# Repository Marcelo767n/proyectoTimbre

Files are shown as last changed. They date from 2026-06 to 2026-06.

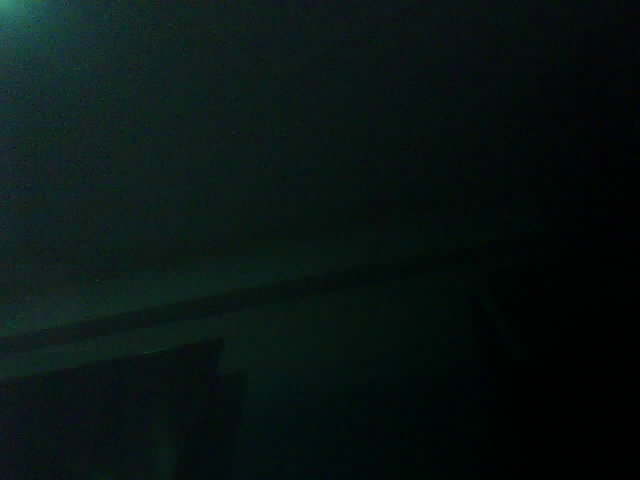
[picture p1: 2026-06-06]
capturas/foto_timbre_20260605_232243.jpg

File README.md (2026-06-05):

# 🔔 Proyecto Timbre Inteligente

Repositorio oficial con la documentación, diseño y código del prototipo de timbre inteligente. Este proyecto se desarrolla para las materias de **Sistemas Embebidos 2** y **Prototipado Rápido**.

---

## 🎯 Objetivo del Proyecto

Diseñar y construir el prototipo de un timbre inteligente basado en una placa de circuito impreso (PCB) personalizada. El sistema captura la presencia de visitantes y gestiona la información de forma remota a través de una interfaz web centralizada.

---

## ⚙️ Arquitectura del Sistema

El proyecto destaca por su capacidad de comunicación remota. Los módulos **no necesitan estar conectados a la misma red Wi-Fi**, ya que la transferencia de datos se realiza a través de Internet.

### 1. Módulo del Timbre (Cliente)
* **Hardware:** ESP32-CAM integrado en una PCB propia diseñada en **KiCad**.
* **Firmware:** Desarrollado en el framework profesional **ESP-IDF** utilizando el entorno de **PlatformIO**.
* **Función:** Al presionar el timbre, el dispositivo se conecta a la red Wi-Fi local (Red A), captura una fotografía del visitante y la envía mediante una petición **HTTP POST** hacia el servidor remoto.

### 2. Módulo de Gestión (Servidor e Interfaz Web)
* **Hardware:** Raspberry Pi.
* **Backend:** Desarrollado en **Python**. Actúa como servidor web central conectado a Internet (Red B) para recibir las peticiones HTTP del timbre y procesar las imágenes.
* **Frontend:** Cuenta con una **interfaz web dedicada** que permite visualizar las fotografías tomadas y consultar los datos de los visitantes en tiempo real.
* **Almacenamiento:** Guarda el historial de visitas de forma estructurada en archivos independientes con formato `.csv` (un archivo `.csv` por cada timbre registrado).

---

## 📊 Datos Registrados

Por cada interacción con el timbre, el sistema procesa y despliega en la interfaz web:
* 📸 Fotografía del visitante.
* 📅 Fecha y hora exacta del evento.
* 🆔 Identificador único del timbre (soporte multi-timbre).

---

## 🛠️ Tecnologías y Herramientas

* **Hardware Base:** ESP32-CAM & Raspberry Pi
* **Diseño Electrónico:** KiCad (Diseño y ruteo de la placa PCB)
* **Entorno de Desarrollo (Firmware):** PlatformIO + ESP-IDF (C/C++)
* **Entorno de Desarrollo (Servidor):** Python
* **Protocolo de Comunicación:** HTTP (Transmisión optimizada de imágenes y metadatos)
* **Base de Datos:** Archivos de texto plano (.CSV) independientes por dispositivo

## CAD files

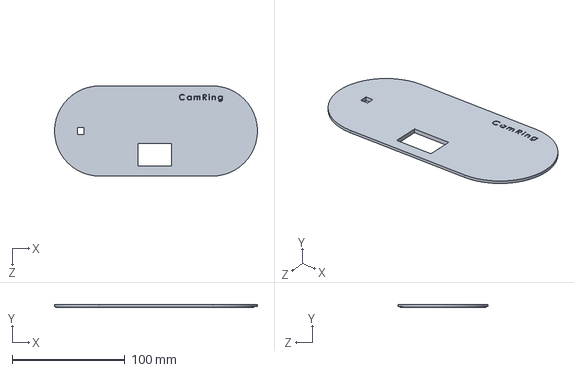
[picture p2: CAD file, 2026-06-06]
diseñoCarcasa/tapa.SLDPRT
180.0 x 3.00 x 80.0 mm

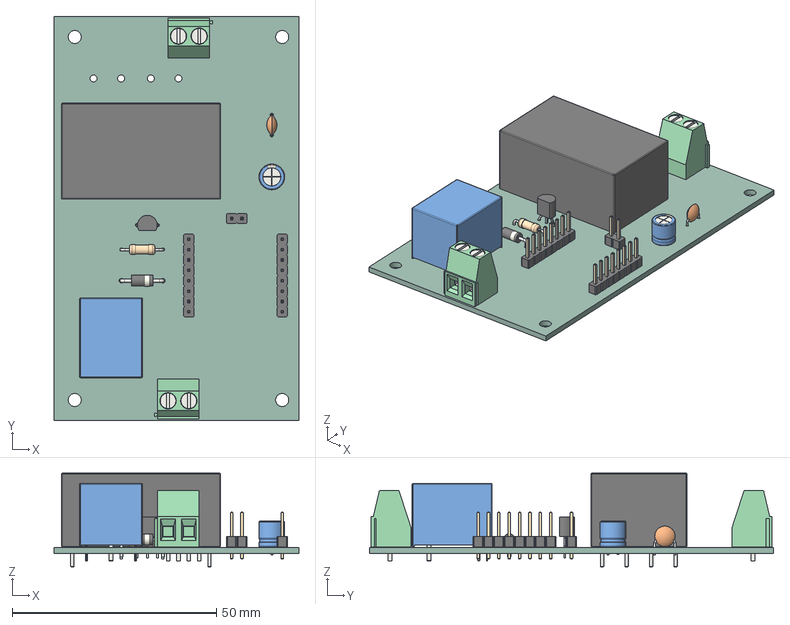
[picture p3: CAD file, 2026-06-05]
pcb/placaTimbre/placaTimbre.step
60.0 x 99.1 x 23.0 mm
D_DO-41_SOD81_P10.16mm_Horizontal
TO-92_Inline_Wide
PinHeader_1x08_P2.54mm_Vertical x 2
Converter_ACDC_Hi-Link_HLK-5Mxx
TerminalBlock_Phoenix_MKDS-1,5-2-5.08_1x02_P5.08mm_Horizontal x 2
PinHeader_1x02_P2.54mm_Vertical
CP_Radial_D6.3mm_P2.50mm
R_Axial_DIN0207_L6.3mm_D2.5mm_P10.16mm_Horizontal
Relay_SPDT_SANYOU_SRD_Series_Form_C
C_Disc_D5.0mm_W2.5mm_P5.00mm
placaTimbre_PCB

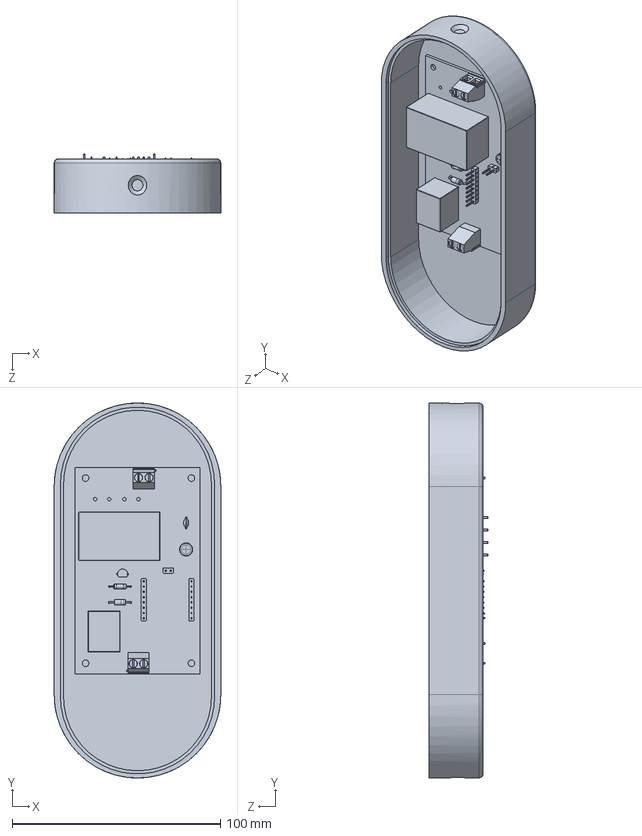
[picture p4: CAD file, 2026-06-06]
diseñoCarcasa/timbre1.SLDPRT
80.0 x 180.0 x 28.3 mm

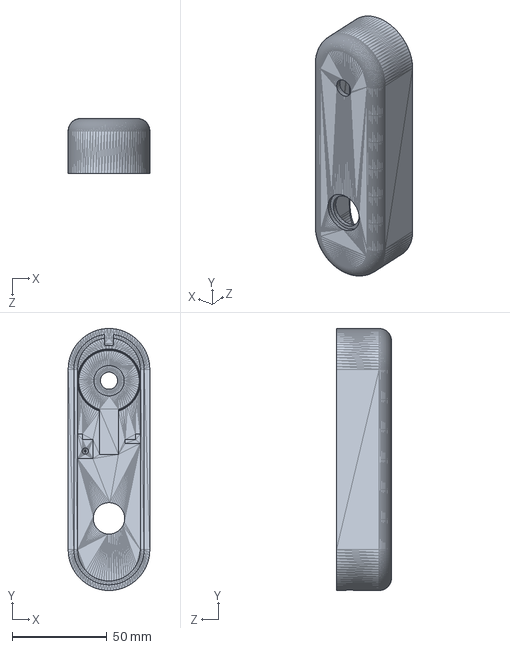
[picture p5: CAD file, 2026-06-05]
diseñoCarcasa/doorbell front v12.SLDPRT
43.0 x 138.0 x 29.0 mm

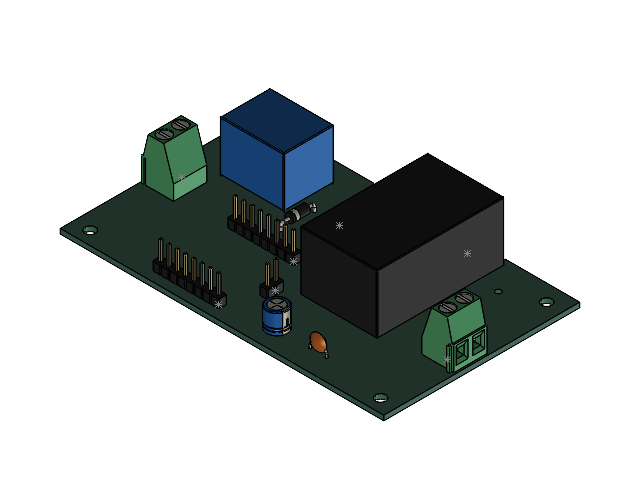
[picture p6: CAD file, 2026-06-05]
diseñoCarcasa/placaTimbre.SLDASM
D_DO-41_SOD81_P10.16mm_Horizontal.step
TO-92_Inline_Wide.step
PinHeader_1x08_P2.54mm_Vertical.step x 2
Converter_ACDC_Hi-Link_HLK-5Mxx.step
TerminalBlock_Phoenix_MKDS-1,5-2-5.08_1x02_P5.08mm_Horizontal.step x 2
PinHeader_1x02_P2.54mm_Vertical.step
CP_Radial_D6.3mm_P2.50mm.step
R_Axial_DIN0207_L6.3mm_D2.5mm_P10.16mm_Horizontal.step
Relay_SPDT_SANYOU_SRD_Series_Form_C.step
C_Disc_D5.0mm_W2.5mm_P5.00mm.step
placaTimbre_PCB.step

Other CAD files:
diseñoCarcasa/timbre.SLDPRT
diseñoCarcasa/placaTimbre.SLDPRT

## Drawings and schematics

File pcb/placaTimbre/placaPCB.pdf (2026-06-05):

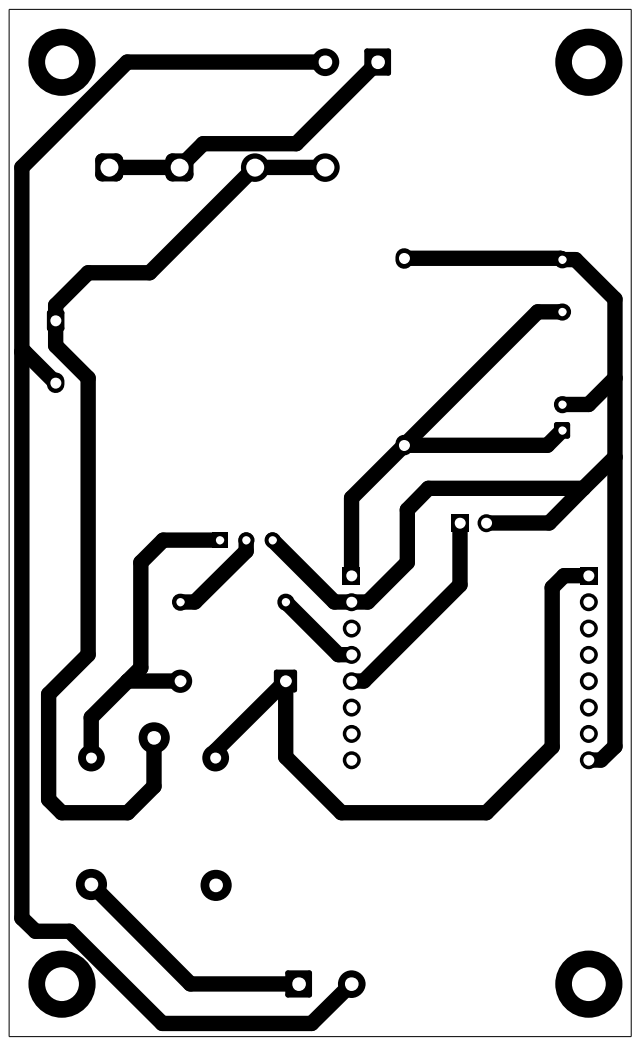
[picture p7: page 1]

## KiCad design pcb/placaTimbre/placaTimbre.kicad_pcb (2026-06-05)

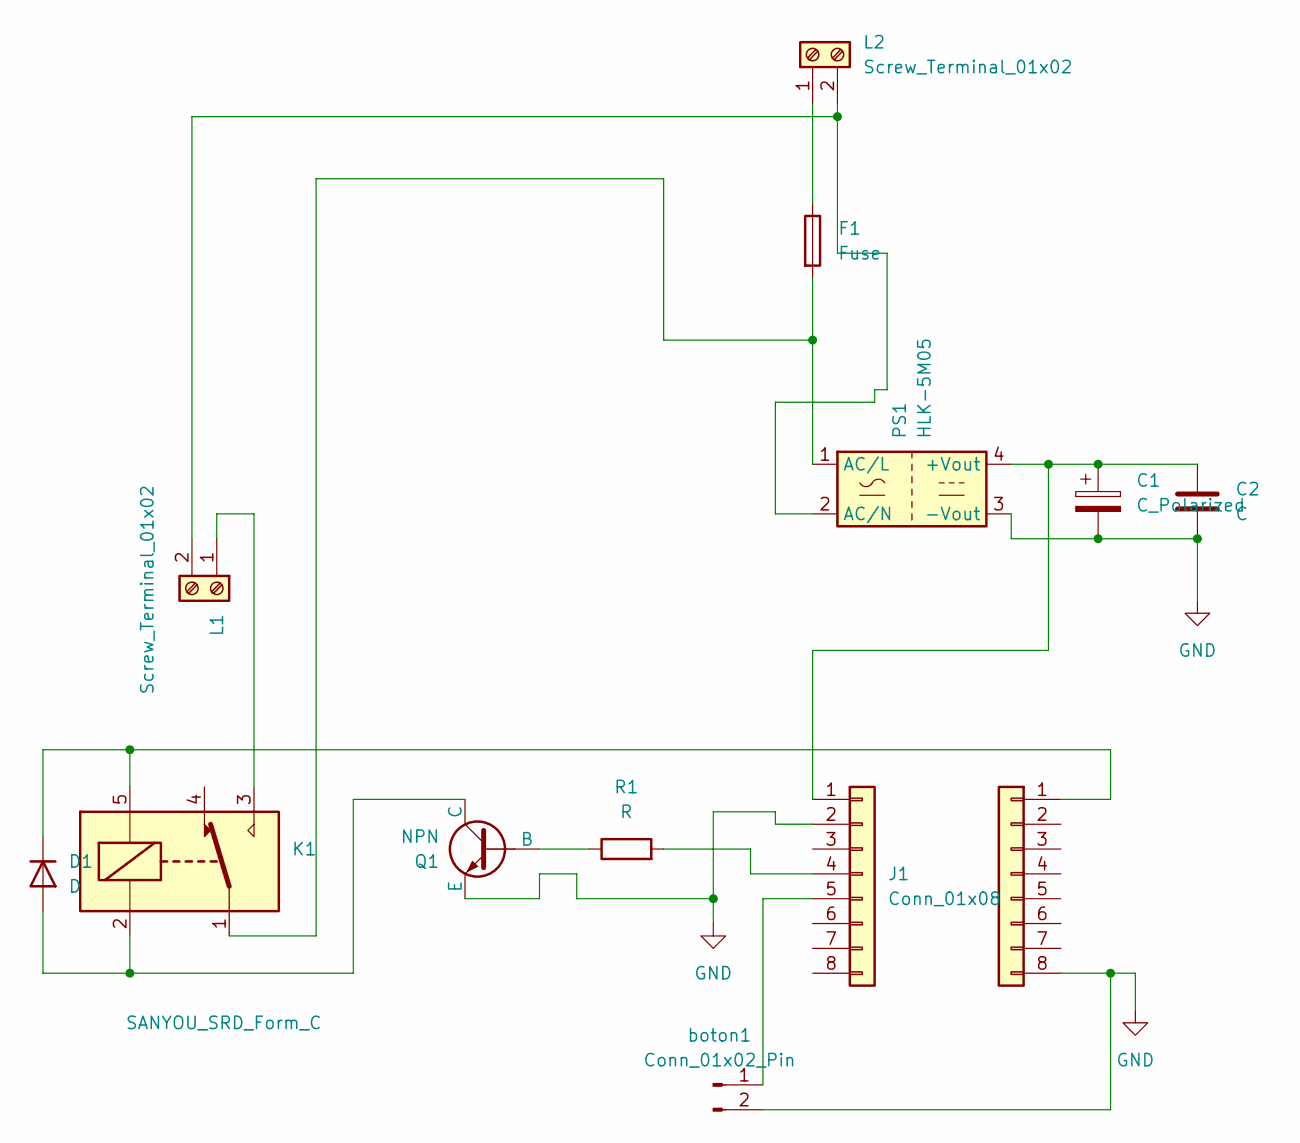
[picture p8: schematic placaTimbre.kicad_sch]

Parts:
C1: C_Polarized; CP_Radial_D6.3mm_P2.50mm
C2: C; C_Disc_D5.0mm_W2.5mm_P5.00mm
D1: D; D_DO-41_SOD81_P10.16mm_Horizontal
F1: Fuse; Fuseholder_Clip-5x20mm_Eaton_1A5601-01_Inline_P20.80x6.76mm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
J1, J2: Conn_01x08; PinHeader_1x08_P2.54mm_Vertical
K1: SANYOU_SRD_Form_C; Relay_SPDT_SANYOU_SRD_Series_Form_C
L1, L2: Screw_Terminal_01x02; TerminalBlock_Phoenix_MKDS-1,5-2-5.08_1x02_P5.08mm_Horizont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
PS1: HLK-5M05; Converter_ACDC_Hi-Link_HLK-5Mxx
Q1: NPN; TO-92_Inline_Wide
R1: R; R_Axial_DIN0207_L6.3mm_D2.5mm_P10.16mm_Horizontal
boton1: Conn_01x02_Pin; PinHeader_1x02_P2.54mm_Vertical

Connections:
GND: C1.2, C2.2, J1.2, J2.8, PS1.3 (-Vout), Q1.3 (E), boton1.2
unnamed: D1.2 (A), K1.2, Q1.1 (C)
unnamed: D1.1 (K), J2.1, K1.5
unnamed: C1.1, C2.1, J1.1, PS1.4 (+Vout)
unnamed: J1.4, R1.2
unnamed: J1.5, boton1.1
unnamed: K1.3, L1.1
unnamed: L1.2, L2.2, PS1.2 (AC/N)
unnamed: F1.1, L2.1
unnamed: F1.2, K1.1, PS1.1 (AC/L)
unnamed: Q1.2 (B), R1.1

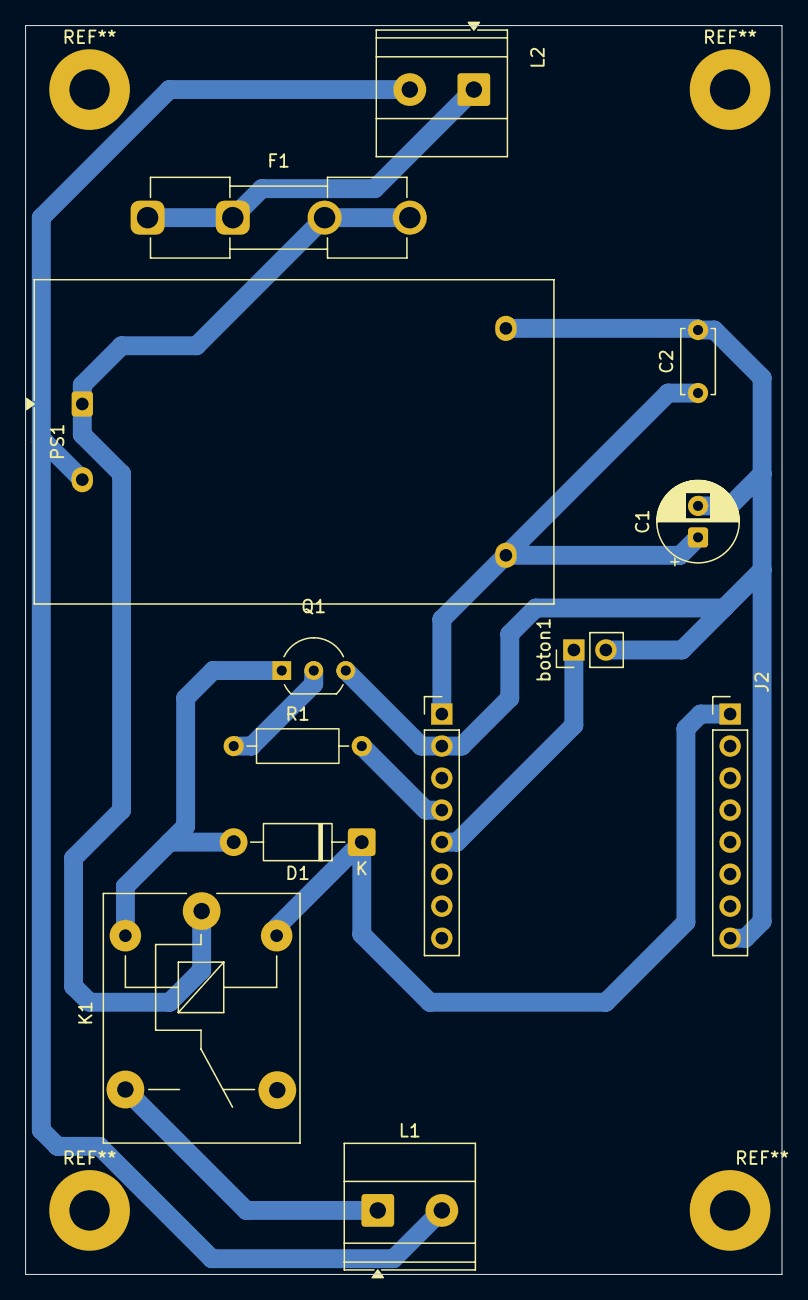
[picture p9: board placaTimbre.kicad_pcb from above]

Board: 2 copper layers, 60.0 x 99.1 mm, 13 parts (0 on the bottom side), 11 nets.

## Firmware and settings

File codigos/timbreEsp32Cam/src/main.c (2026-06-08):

#include <stdio.h>
#include "freertos/FreeRTOS.h"
#include "freertos/task.h"
#include "nvs_flash.h"
#include "esp_log.h"

#include "conexion.h"
#include "funciones.h"

void app_main(void) {
    printf("==================================\n");
    printf("   TIMBRE IOT - ARQUITECTURA 2.0  \n");
    printf("==================================\n");

    // 1. Iniciar NVSer
    esp_err_t ret = nvs_flash_init();
    if (ret == ESP_ERR_NVS_NO_FREE_PAGES || ret == ESP_ERR_NVS_NEW_VERSION_FOUND) {
      ESP_ERROR_CHECK(nvs_flash_erase());
      ret = nvs_flash_init();
    }
    ESP_ERROR_CHECK(ret);

    // 2. Iniciar Red
    init_wifi();

    // 3. Iniciar Mecatrónica y Visión
    init_hardware();
    init_camara();

    // 4. Lanzar tareas
    xTaskCreate(tarea_timbre, "Tarea_Timbre", 4096, NULL, 10, NULL);

    // ==========================================
    // SIMULACIÓN DE HARDWARE (TEST AUTOMÁTICO)
    // ==========================================
    ESP_LOGW("TEST", "Esperando 8 segundos para el auto-disparo...");
    vTaskDelay(pdMS_TO_TICKS(8000)); 
    
    uint32_t pin_simulado = PIN_BOTON;
    // Inyectamos la señal virtual directo al cerebro de la tarea
    xQueueSend(cola_timbre, &pin_simulado, portMAX_DELAY);
}

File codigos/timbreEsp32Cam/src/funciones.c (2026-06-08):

#include "funciones.h"
#include "esp_camera.h"
#include "esp_http_client.h"
#include "esp_log.h"
#include "driver/gpio.h"
#include "freertos/FreeRTOS.h"
#include "freertos/task.h"
#include "freertos/queue.h"

static const char *TAG = "TIMBRE_HARDWARE";

// Instancia de la cola definida en el .h
QueueHandle_t cola_timbre = NULL;

// ==========================================
// INICIALIZACIÓN DE HARDWARE (Botón y Relé)
// ==========================================
void init_hardware(void) {
    ESP_LOGI(TAG, "Inicializando hardware mecatrónico...");
    
    // Crear la cola de FreeRTOS para la comunicación de eventos (10 espacios)
    cola_timbre = xQueueCreate(10, sizeof(uint32_t));
    
    // Configurar el pin del Botón como entrada
    gpio_config_t conf_boton = {
        .pin_bit_mask = (1ULL << PIN_BOTON),
        .mode = GPIO_MODE_INPUT,
        .pull_up_en = GPIO_PULLUP_DISABLE,
        .pull_down_en = GPIO_PULLDOWN_ENABLE, 
        .intr_type = GPIO_INTR_DISABLE
    };
    gpio_config(&conf_boton);

    // Configurar el pin del Relé como salida
    gpio_config_t conf_rele = {
        .pin_bit_mask = (1ULL << PIN_RELE),
        .mode = GPIO_MODE_OUTPUT,
        .pull_up_en = GPIO_PULLUP_DISABLE,
        .pull_down_en = GPIO_PULLDOWN_DISABLE,
        .intr_type = GPIO_INTR_DISABLE
    };
    gpio_config(&conf_rele);
    gpio_set_level(PIN_RELE, 0); // Asegurar que arranque apagado

    // Configurar el Flash
    gpio_set_direction(PIN_FLASH, GPIO_MODE_OUTPUT);
    gpio_set_level(PIN_FLASH, 0);
}

// ==========================================
// INICIALIZACIÓN DE LA CÁMARA (AI-Thinker)
// ==========================================
void init_camara(void) {
    ESP_LOGI(TAG, "Inicializando módulo de cámara...");
    
    camera_config_t config;
    config.ledc_channel = LEDC_CHANNEL_0;
    config.ledc_timer = LEDC_TIMER_0;
    config.pin_d0 = CAM_PIN_Y2;
    config.pin_d1 = CAM_PIN_Y3;
    config.pin_d2 = CAM_PIN_Y4;
    config.pin_d3 = CAM_PIN_Y5;
    config.pin_d4 = CAM_PIN_Y6;
    config.pin_d5 = CAM_PIN_Y7;
    config.pin_d6 = CAM_PIN_Y8;
    config.pin_d7 = CAM_PIN_Y9;
    config.pin_xclk = CAM_PIN_XCLK;
    config.pin_pclk = CAM_PIN_PCLK;
    config.pin_vsync = CAM_PIN_VSYNC;
    config.pin_href = CAM_PIN_HREF;
    config.pin_sccb_sda = CAM_PIN_SIOD;
    config.pin_sccb_scl = CAM_PIN_SIOC;
    config.pin_pwdn = CAM_PIN_PWDN;
    config.pin_reset = CAM_PIN_RESET;
    config.xclk_freq_hz = 20000000;
    config.pixel_format = PIXFORMAT_JPEG; 

    // Configuración segura y rápida para la red
    config.frame_size = FRAMESIZE_VGA; 
    config.jpeg_quality = 12;
    config.fb_count = 1;

    esp_err_t err = esp_camera_init(&config);
    if (err != ESP_OK) {
        ESP_LOGE(TAG, "Fallo al iniciar cámara: 0x%x", err);
    }
}

// ==========================================
// ENVÍO HTTP A LA RASPBERRY PI
// ==========================================
void enviar_foto_servidor(camera_fb_t *fb) {
    ESP_LOGI(TAG, "Enviando imagen a Raspberry Pi...");
    
    esp_http_client_config_t config = {
        // IP DEL POCO F5 ACTUALIZADA AQUÍ
        .url = "http://10.241.61.199:8000/upload?id=Timbre_Principal", 
        .method = HTTP_METHOD_POST,
        .skip_cert_common_name_check = true, 
    };

    esp_http_client_handle_t client = esp_http_client_init(&config);
    esp_http_client_set_header(client, "Content-Type", "image/jpeg");
    esp_http_client_set_post_field(client, (const char *)fb->buf, fb->len);

    esp_err_t err = esp_http_client_perform(client);
    if (err == ESP_OK) {
        ESP_LOGI(TAG, "✅ Imagen enviada. Código HTTP: %d", esp_http_client_get_status_code(client));
    } else {
        ESP_LOGE(TAG, "❌ Error HTTP: %s", esp_err_to_name(err));
    }
    esp_http_client_cleanup(client);
}

// ==========================================
// TAREA PRINCIPAL (Cerebro del Sistema)
// ==========================================
void tarea_timbre(void *pvParameters) {
    uint32_t pin_evento;

    while (1) {
        // Escucha tanto el botón físico como la simulación automática de main.c
        if (gpio_get_level(PIN_BOTON) == 1 || xQueueReceive(cola_timbre, &pin_evento, 0) == pdTRUE) {
            ESP_LOGI(TAG, "¡Alarma disparada! Iniciando captura...");

            gpio_set_level(PIN_FLASH, 1);
            vTaskDelay(pdMS_TO_TICKS(500)); // Estabilizar luz

            camera_fb_t *fb = esp_camera_fb_get();
            if (fb) {
                gpio_set_level(PIN_FLASH, 0); // Apagar inmediatamente
                enviar_foto_servidor(fb);
                esp_camera_fb_return(fb); // Liberar RAM (Vital)
            } else {
                ESP_LOGE(TAG, "Fallo al capturar imagen");
                gpio_set_level(PIN_FLASH, 0);
            }

            ESP_LOGI(TAG, "Entrando en recarga térmica (5 segundos)...");
            vTaskDelay(pdMS_TO_TICKS(5000)); 
        }
        
        vTaskDelay(pdMS_TO_TICKS(100)); // Evitar saturar el procesador
    }
}

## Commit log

2026-06-05 creacion de carpetas y diseno de la placa pcb
    [doorbell front v12.SLDPRT, placaTimbre.SLDASM, placaTimbre.SLDPRT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]
2026-06-05 prueba de archivos main.c y demas en platformio
2026-06-05 prueba de wifi de esp32 cam
2026-06-05 arreglo de conexion wifi y cambios en archivo .ini
    [funciones.h]
2026-06-05 mejor modularizacion y wifi para usuarios
2026-06-05 mejora de interfaz para usuario wifi
2026-06-05 correccion a la conectividad wifi
2026-06-05 inicializacion de los paquete de camara
2026-06-05 organizacion de carpetas
2026-06-06 cambios en la placa y diseno de carcasa
    [tapa.SLDPRT, timbre1.SLDPRT]
2026-06-06 particiones de memoria, envio de fotos remotante
    [partitions.csv]
2026-06-06 primera foto enviada de esp32 a raspberry, instalacion de cloudflare
2026-06-08 actualizacion de codigo
2026-06-08 cambio de red wifi
